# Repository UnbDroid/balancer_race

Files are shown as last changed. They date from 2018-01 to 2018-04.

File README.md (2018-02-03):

# Balancing Robot Race - RoboGames 2019

This is the Git repository containing all documents, code and schematics
used in the construction of DROID's robot.

### Cross-Compiling

Available at ```/ccdir```, the ```compile_rasp.sh``` file contains a script for
cross-compiling C code for the Raspberry Pi. It is a much faster process
than compiling code directly at the Raspberry.

Run ```$ sudo apt install gcc-arm-linux-gnueabi``` to install the ARM11 GCC.

All the library files needed must be provided. In this particular case,
we put them all in the same directory as the main code.

### Main Code and Threading

The main code, available at the ```main.c``` file under ```/code```, uses the ```pthread```
wrapper provided by the WiringPi library to parallelize the execution of the
code modules. Reference and documentation available at [WiringPi website](http://www.wiringpi.com).

### Information about DROID-UnB

DROID is a robotic competion team based in the university of Brasília - UnB.

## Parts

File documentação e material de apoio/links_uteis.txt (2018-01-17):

código para gyroscópio e acelerometro usando filtro de kalman:
https://github.com/TKJElectronics/Example-Sketch-for-IMU-including-Kalman-filter/tree/master/IMU/MPU6050
##obs: é o código referência para a criação do código mpu6050kalman.c em ~/testes.

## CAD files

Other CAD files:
documentação e material de apoio/motion_driver_6.12/msp430/eMD-6.0/Debug/core/driver/eMPL/inv_mpu_dmp_motion_driver.obj
documentação e material de apoio/motion_driver_6.12/msp430/eMD-6.0/Debug/core/driver/msp430/F5xx_F6xx_Core_Lib/HAL_PMM.obj
documentação e material de apoio/motion_driver_6.12/msp430/eMD-6.0/Debug/core/driver/msp430/msp430_interrupt.obj
documentação e material de apoio/motion_driver_6.12/msp430/eMD-6.0/Debug/core/driver/msp430/USB_API/USB_CDC_API/UsbCdc.obj
documentação e material de apoio/motion_driver_6.12/msp430/eMD-6.0/Debug/core/driver/msp430/USB_API/USB_Common/dma.obj
documentação e material de apoio/motion_driver_6.12/msp430/eMD-6.0/Debug/core/driver/msp430/USB_API/USB_HID_API/UsbHid.obj
documentação e material de apoio/motion_driver_6.12/msp430/eMD-6.0/Debug/core/driver/msp430/USB_API/USB_MSC_API/UsbMscStateMachine.obj
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

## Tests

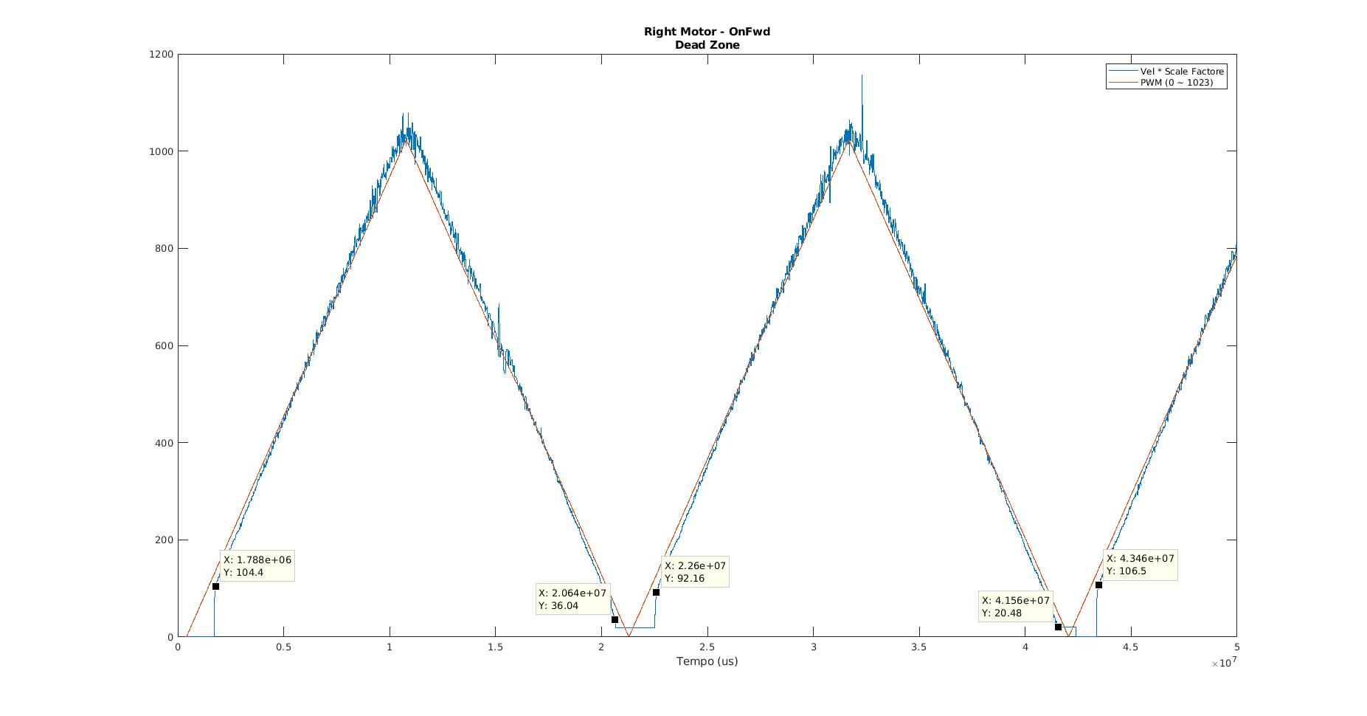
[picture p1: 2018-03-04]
MATLAB/plots/EncoderTest/dead_zone/Right Motor - OnFwd - DZ.jpg

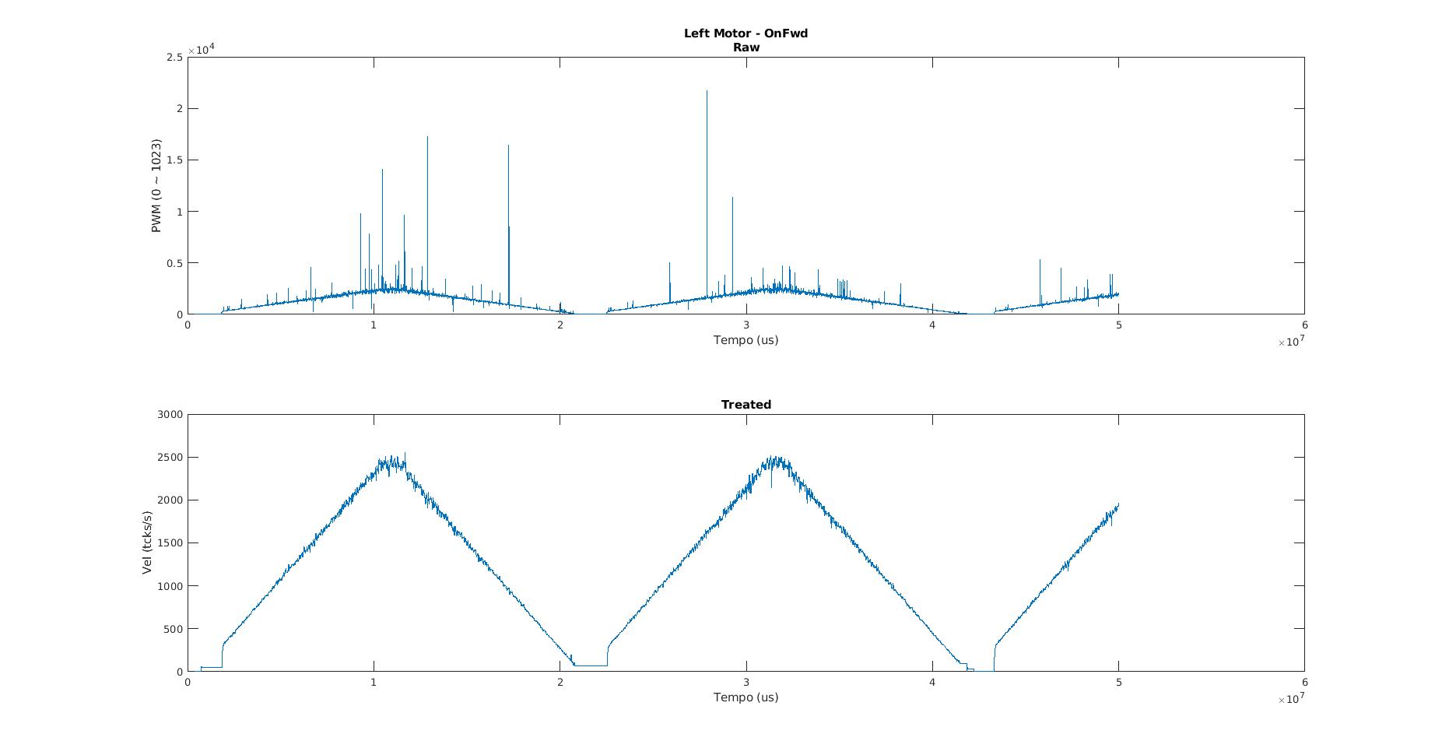
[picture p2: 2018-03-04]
MATLAB/plots/EncoderTest/dead_zone/Left Motor - OnFwd - tratamento.jpg

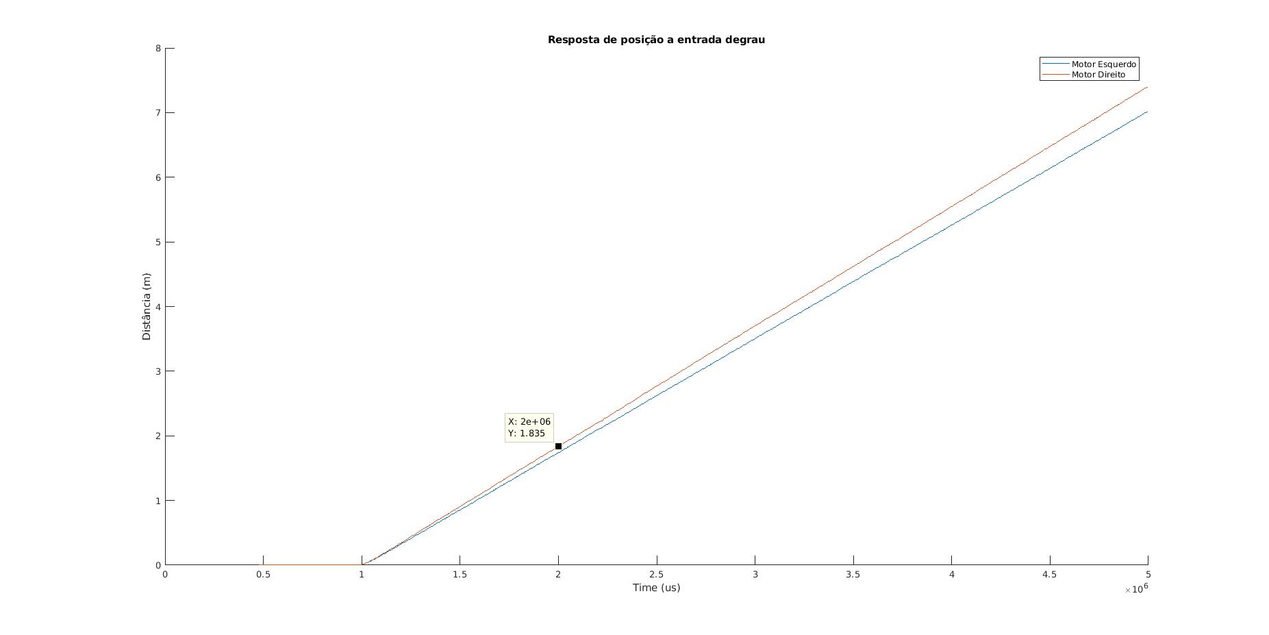
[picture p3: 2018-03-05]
MATLAB/plots/EncoderTest/posicao/degrau.jpg

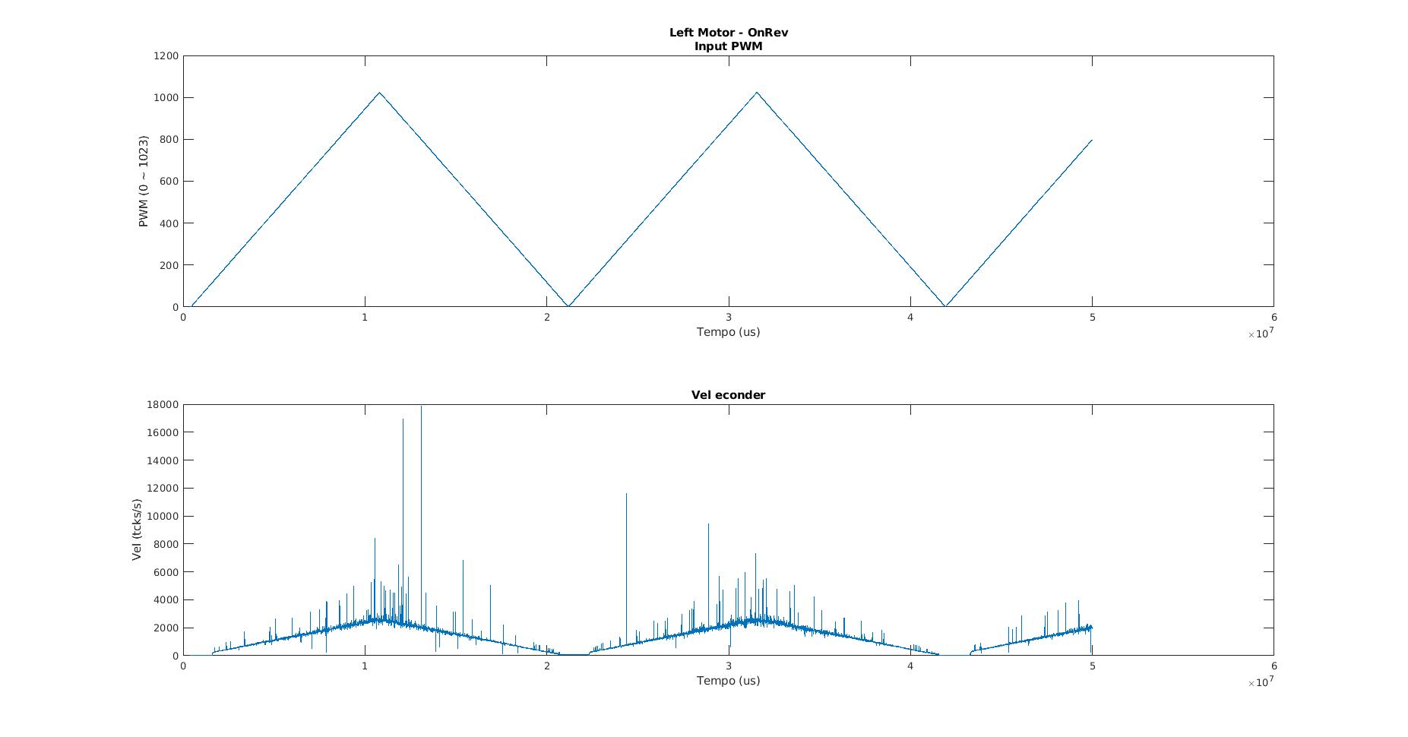
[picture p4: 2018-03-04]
MATLAB/plots/EncoderTest/dead_zone/Left Motor - OnRev - Raw.jpg

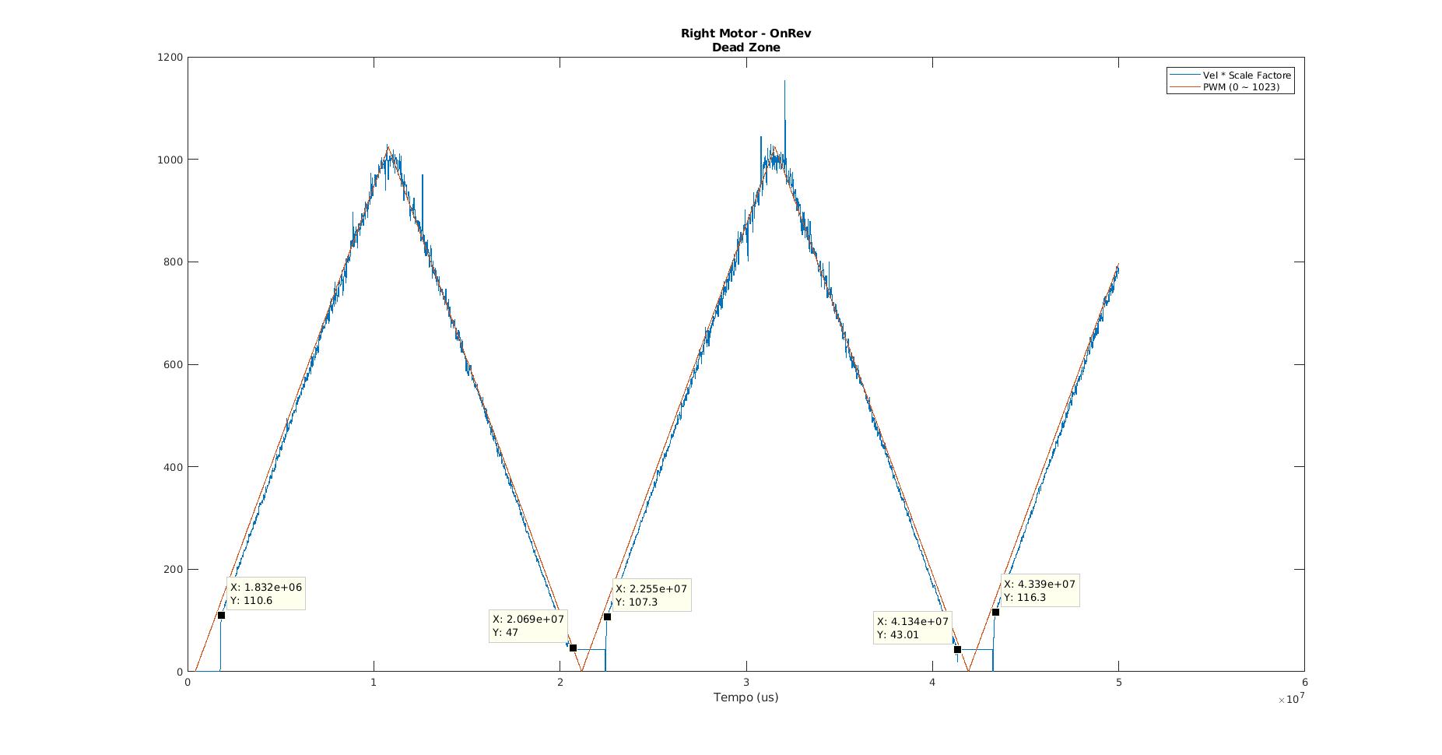
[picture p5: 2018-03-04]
MATLAB/plots/EncoderTest/dead_zone/Right Motor - OnRev - DZ.jpg

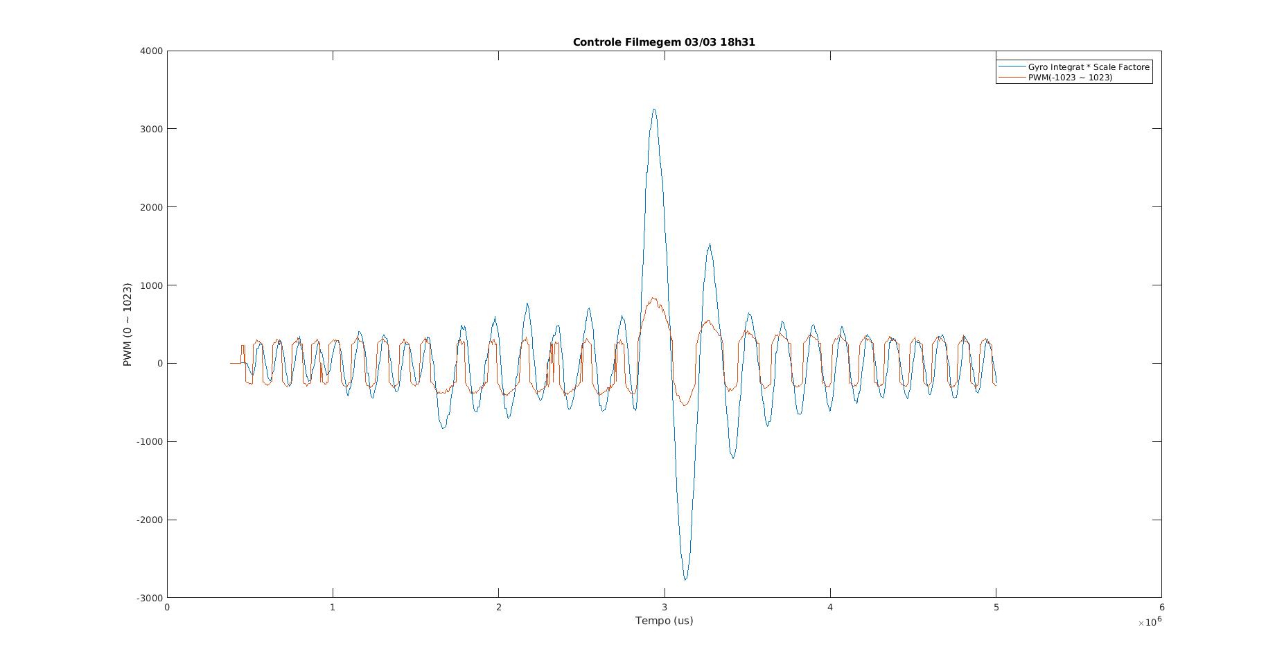
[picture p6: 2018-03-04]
MATLAB/plots/EncoderTest/controle/18h31.jpg

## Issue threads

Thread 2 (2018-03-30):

Fix integrator wind-up problem

bandreghetti, 2018-03-30:
PID integrator winds up if reference step is too big. Also it forces the gears when driver is off.

Proposed solution: integrate only if pwm output is not saturated.

luanharaujo, 2018-03-30:
Da para responder esse email?

Em sex, 30 de mar de 2018 às 17:43, Bruno Andreghetti Dantas <
notifications@github.com> escreveu:

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

Closed 2018-04-09.

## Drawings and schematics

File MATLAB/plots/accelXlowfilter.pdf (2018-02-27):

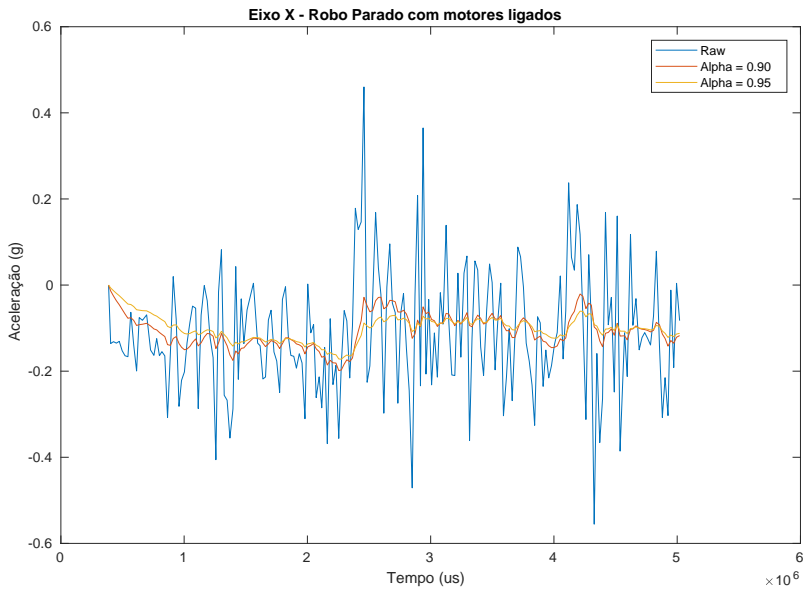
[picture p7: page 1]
Tempo (us); Aceleração (g); Raw Alpha = 0.90 Alpha = 0.95

Eixo X - Robo Parado com motores ligados

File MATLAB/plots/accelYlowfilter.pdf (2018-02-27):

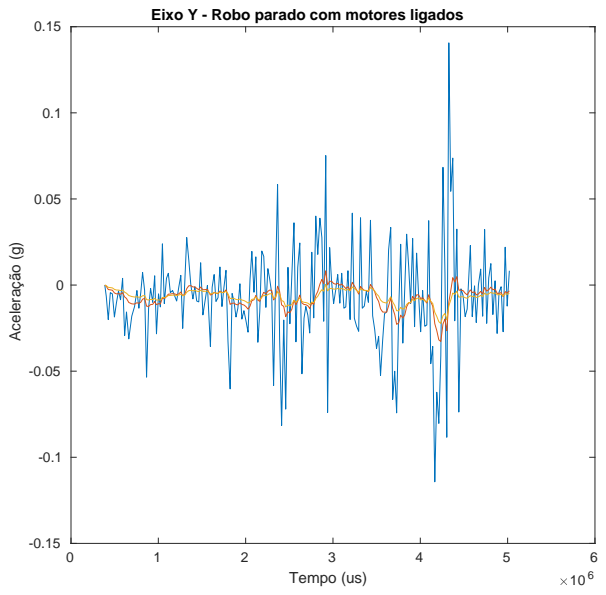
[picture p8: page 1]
Tempo (us); Aceleração (g)

Eixo Y - Robo parado com motores ligados

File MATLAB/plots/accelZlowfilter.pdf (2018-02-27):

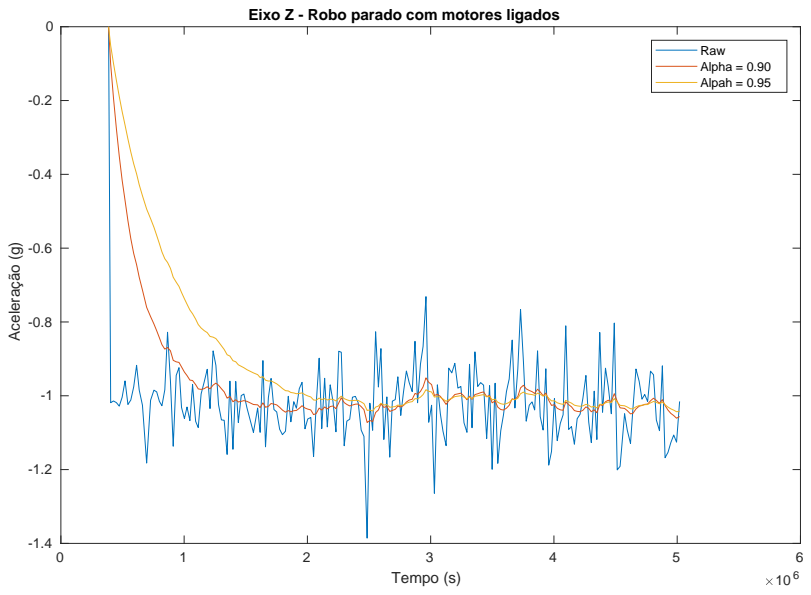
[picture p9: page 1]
Tempo (s); Aceleração (g); Raw Alpha = 0.90 Alpah = 0.95

Eixo Z - Robo parado com motores ligados

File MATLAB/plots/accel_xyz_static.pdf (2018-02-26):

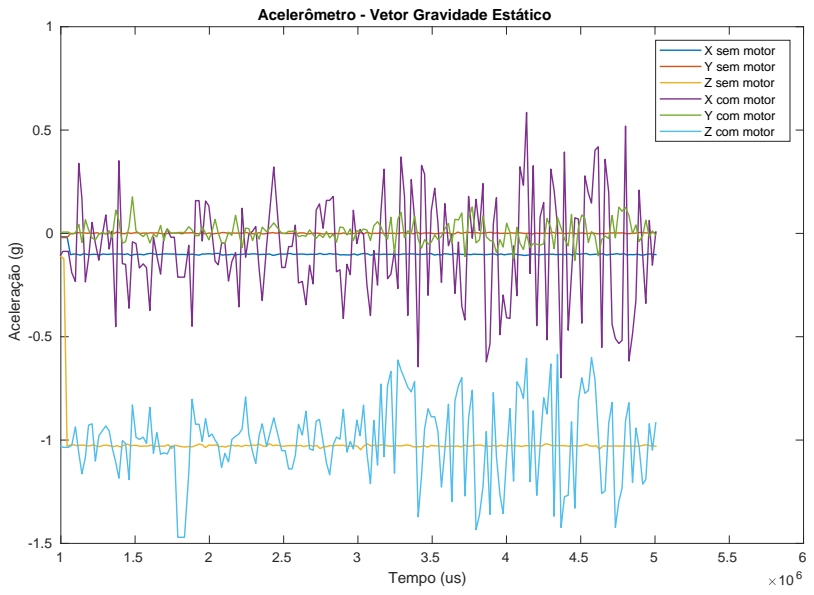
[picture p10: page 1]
Tempo (us); Aceleração (g); X sem motor Y sem motor Z sem motor X com motor Y com motor Z com motor

Acelerômetro - Vetor Gravidade Estático

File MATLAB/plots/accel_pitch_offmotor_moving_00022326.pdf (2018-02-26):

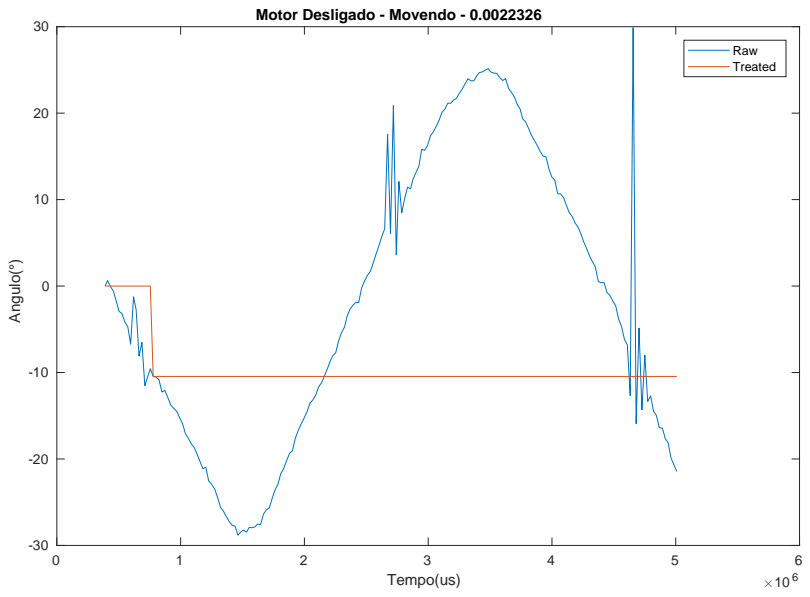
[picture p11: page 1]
Tempo(us); Angulo(°); Raw Treated

Motor Desligado - Movendo - 0.0022326

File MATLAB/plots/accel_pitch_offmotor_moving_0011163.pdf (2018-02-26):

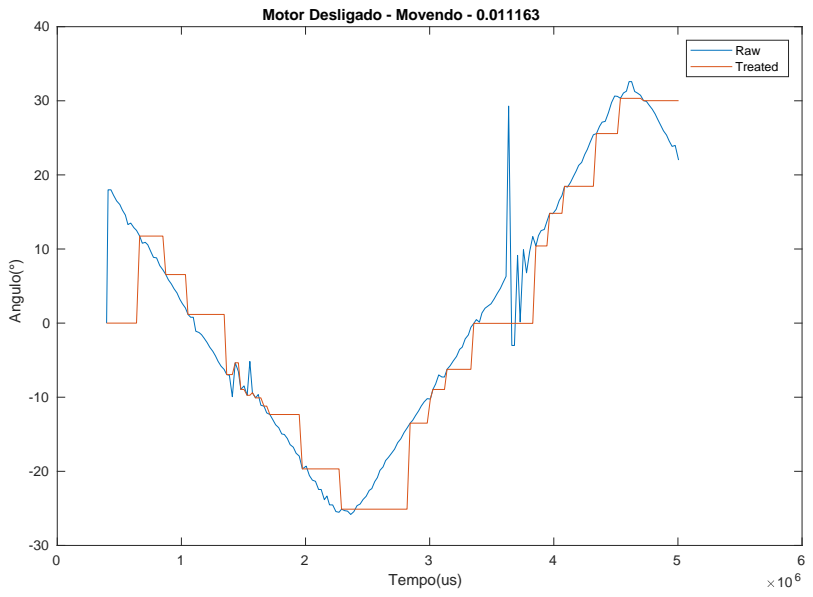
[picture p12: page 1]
Tempo(us); Angulo(°); Raw Treated

Motor Desligado - Movendo - 0.011163

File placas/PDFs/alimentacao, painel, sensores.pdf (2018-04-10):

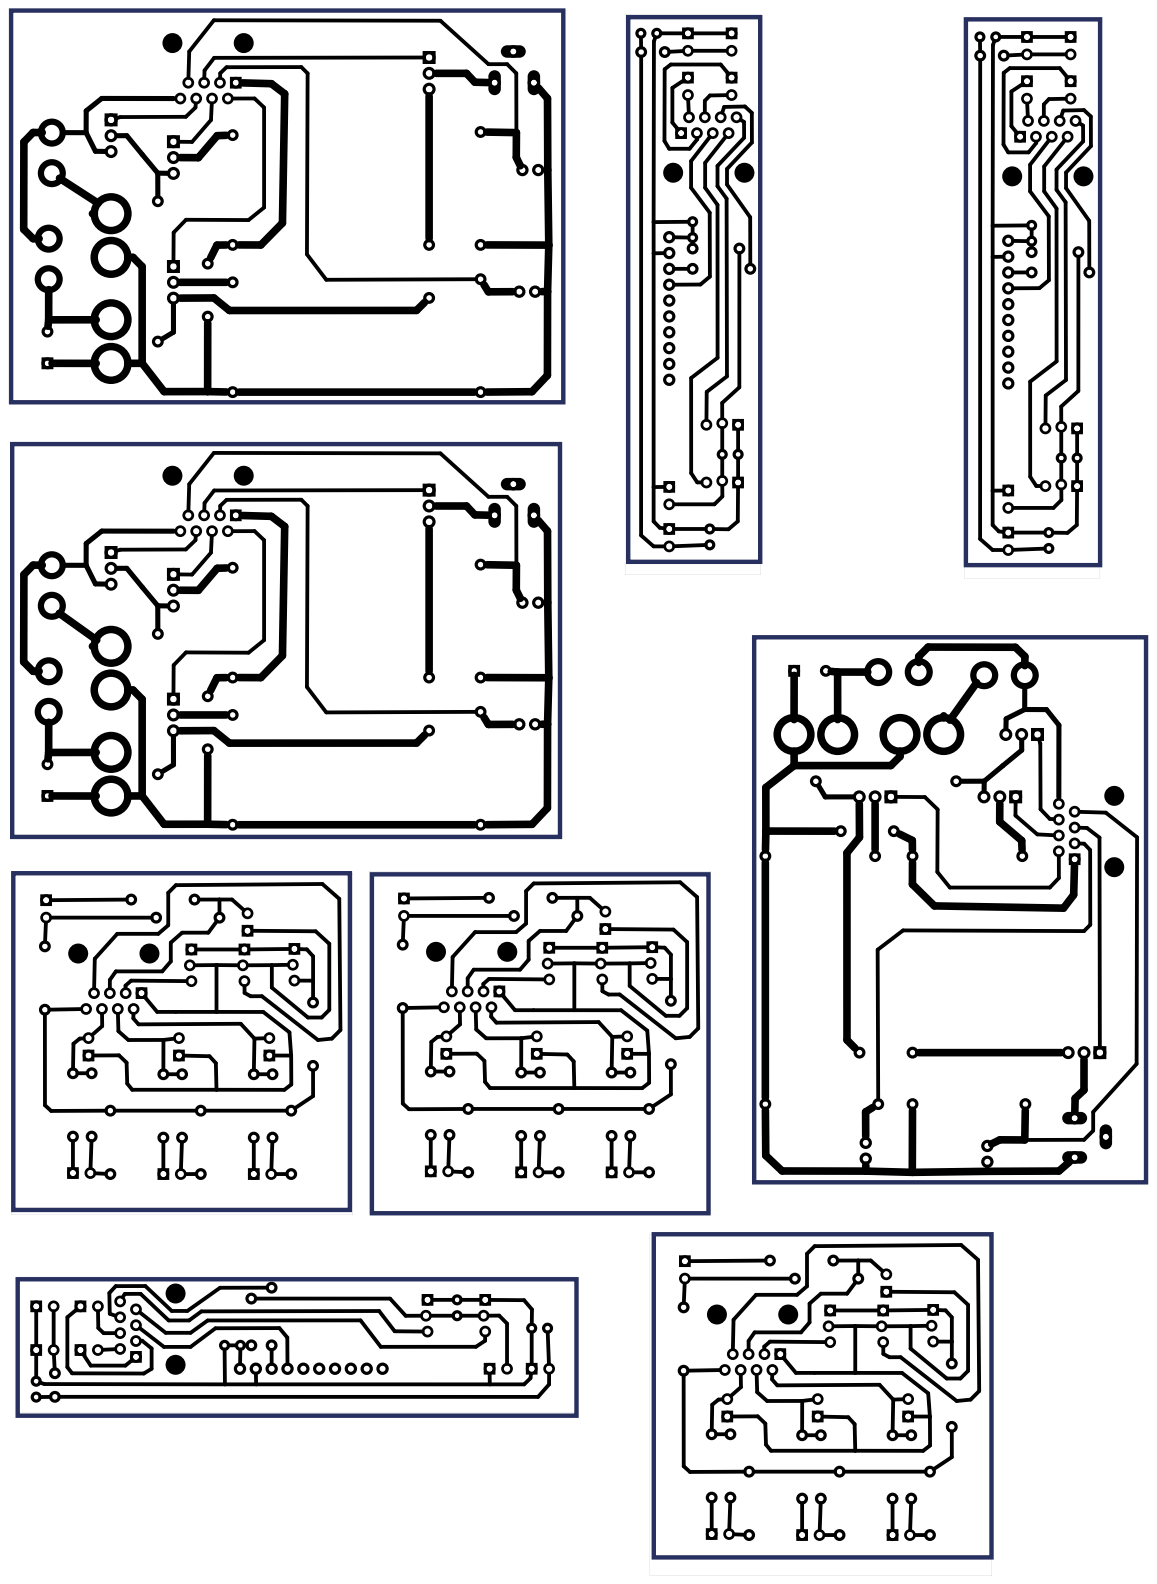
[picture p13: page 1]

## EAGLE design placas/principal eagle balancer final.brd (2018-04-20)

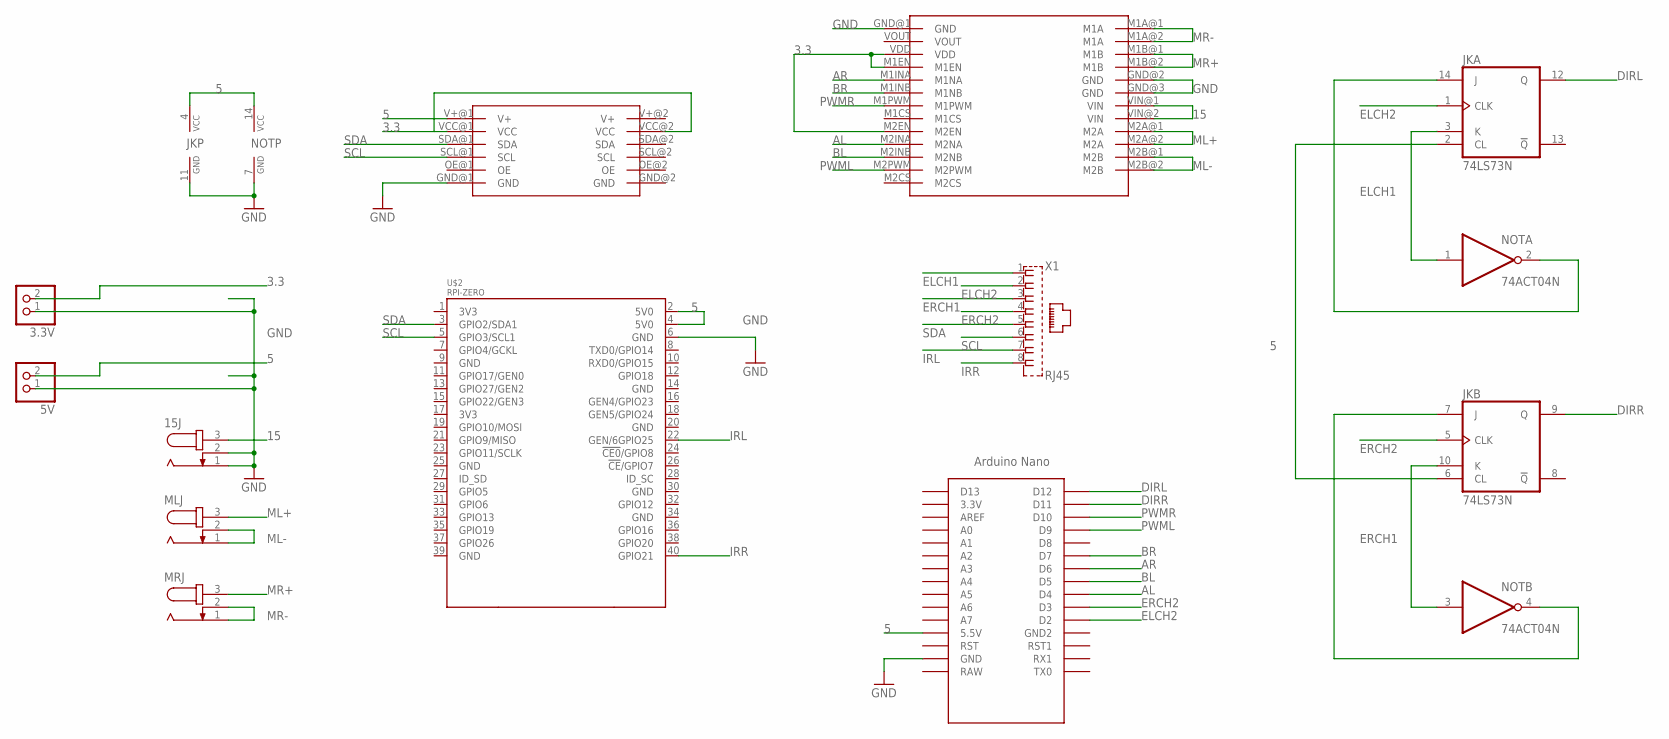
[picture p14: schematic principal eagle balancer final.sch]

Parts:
3.3V, 5V: PINHD-1X2; 1X02
15J: JACK-PLUG1; SPC4078
JK: 74LS73N; DIL14
MLJ: JACK-PLUG1; SPC4078
MRJ: JACK-PLUG1; SPC4078
NOT: 74ACT04N; DIL14
U$1: PCA; PCA_P
U$2: RPI-ZERO; RASPBERRYPI_BASTELSTUBE_V13_RASPI_BOARD_B+_FULL
U$3: VNH5019; VNH5019_P
U$4: NANO
X1: RJ45; RJ45_P

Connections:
3.3: 3.3V.2, U$1.VCC@1 (VCC), U$1.VCC@2 (VCC), U$3.M1EN, U$3.M2EN, U$3.VDD
5: 5V.2, JK.2 (CL), JK.4 (VCC), JK.6 (CL), NOT.14 (VCC), U$1.V+@1 (V+), U$2.2 (5V0), U$2.4 (5V0), U$4.5V (5.5V)
15: 15J.3, U$3.VIN@1 (VIN), U$3.VIN@2 (VIN)
AL: U$3.M2INA (M2NA), U$4.D4
AR: U$3.M1INA (M1NA), U$4.D6
BL: U$3.M2INB (M2NB), U$4.D5
BR: U$3.M1INB (M1NB), U$4.D7
DIRL: JK.12 (Q), U$4.D12
DIRR: JK.9 (Q), U$4.D11
ELCH1: JK.3 (K), NOT.1 (I), X1.1
ELCH2: JK.1 (CLK), U$4.D2, X1.2
ERCH1: JK.10 (K), NOT.3 (I), X1.3
ERCH2: JK.5 (CLK), U$4.D3, X1.4
GND: 3.3V.1, 5V.1, 15J.1, 15J.2, JK.11 (GND), NOT.7 (GND), U$1.GND@1 (GND), U$2.6 (GND), U$3.GND@1 (GND), U$3.GND@2 (GND), U$3.GND@3 (GND), U$4.GND
IRL: U$2.22 (GEN/6GPIO25), X1.7
IRR: U$2.40 (GPIO21), X1.8
ML+: MLJ.3, U$3.M2A@1 (M2A), U$3.M2A@2 (M2A)
ML-: MLJ.1, MLJ.2, U$3.M2B@1 (M2B), U$3.M2B@2 (M2B)
MR+: MRJ.3, U$3.M1B@1 (M1B), U$3.M1B@2 (M1B)
MR-: MRJ.1, MRJ.2, U$3.M1A@1 (M1A), U$3.M1A@2 (M1A)
unnamed: JK.14 (J), NOT.2 (O)
unnamed: JK.7 (J), NOT.4 (O)
PWML: U$3.M2PWM, U$4.D9
PWMR: U$3.M1PWM, U$4.D10
SCL: U$1.SCL@1 (SCL), U$2.5 (GPIO3/SCL1), X1.6
SDA: U$1.SDA@1 (SDA), U$2.3 (GPIO2/SDA1), X1.5

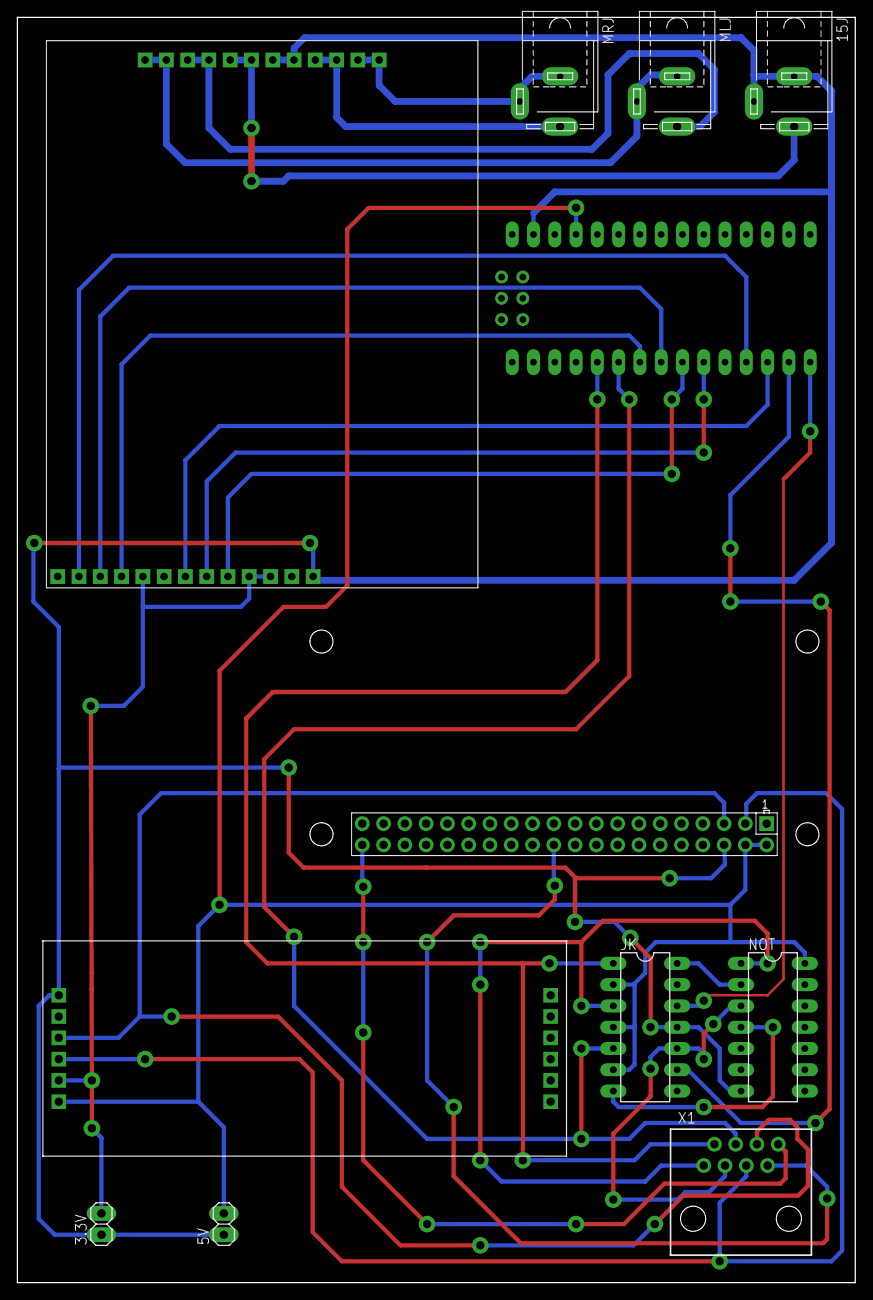
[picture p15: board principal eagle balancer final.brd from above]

Board: 2 copper layers, 100.0 x 151.0 mm, 12 parts (0 on the bottom side), 26 nets.

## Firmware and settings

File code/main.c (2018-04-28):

#include <stdio.h>
#include <stdlib.h>
#include <wiringPi.h>
#include <unistd.h>
#include <string.h>
#include <ctype.h>
#include <math.h>
#include "jstick.c"
#include "led.c"
#include "sensors.c"
#include "motor.c"
#include "debug.c"


struct debug_data debug;	// struct containing all robot values
							// for debugging purposes

int keep_running = 1;	// end of program flag. it is controlled by the
						// joystick thread. if set to 0, all threads will
						// finish up and set their own flags to 1 so that
						// the main program can clean everything up and end.

int main_finished = 1, led_finished = 1, joystick_finished = 1;
int debug_finished = 1, sensors_finished = 1, motors_finished = 1;
int matlab_finished = 1, supervisory_finished = 1, plot_finished = 1;

int shutdown_flag = 0, reboot = 0, close_program=0;	// flags set by joystick
													// commands so that the
													// program knows what to
													// do when finishing up.

int halt = 1;

/*
This is the main thread. In it, we are supposed to put everything that doesn't
belong in the infrastructure threads below it. Generally, it is used to test
new features using the joystick controller.
*/

/*
//Butterworth Filter - A manteiga que vale
#define A0 1.000000000000000
#define A1 -1.968427786938518
#define A2 1.735860709208886
#define A3 -0.724470829507362
#define A4 0.120389599896245
#define B0 0.010209480791203
#define B1 0.040837923164813
#define B2 0.061256884747219
#define B3 0.040837923164813
#define B4 0.010209480791203

double A[5] = {A0, A1, A2, A3, A4};
double B[5] = {B0, B1, B2, B3, B4};
double bw_filtered[4];
double bw_raw[5];
*/

#define DEV_ACC_Z_OVER_X 97.1256
// motor grande
//float KP = 385; //325;
//float KD = 15; //10;
//float KI = 20;

double EULER = 2.718281828459045;

// motor pequeno
float KP = 0.2;//125; //325;
float KD = 0.02;//2.5;
float KI = 0.007;//0.7;

float KPvel = 3.1;//1;//1;
float KDvel = 0.01;//0;//10;
float KIvel = 1.15;//1.7;//5;

float KPome = 1;
float KDome = 0.025;
float KIome = 2;

float teta = 0, teta_linha, teta_raw;
float gyroIntegrate = 0, old_gyroIntegrate = 0;
int pot = 0, dir;
float GK;
float dev_teta;
unsigned long long int temp = 0;
int flag;
float tetaIntegrat = 0;


// VARIAVEIS USADAS NO CONTROLE.
double speed = 0;

double vel_ref = 0;
double vel_erro = 0, vel_erro_old = 0, vel_erro_integrate = 0, vel_ref_integrate = 0, vel_erro_derivate = 0;
double vel_med = 0;
unsigned long long int vel_time, vel_time_old, vel_dt;

double req_tilt = 0, req_tilt_old = 0, req_tilt_linha = 0;
double tilt_erro = 0, tilt_erro_integrate = 0, tilt_erro_linha = 0;

double omega = 0, omega_integrate = 0, omega_ref_integrate = 0;
double omega_erro = 0, omega_erro_old = 0, omega_erro_integrate = 0, omega_erro_derivate = 0;
double speed_dir = 0;
double omega_ref = 0;

unsigned long long int ref_crono = 0, ref_crono_set = 0, ref_time = 0;
double diff = 0, ref = 0, atual = 0, ref_old = 0;
double time_k = 38.918203; // ln(1-%a/%a)/-ta // %a = porcentagem que deseja obter apos decorrido tempo ta. ta = tempo necessario para chegar na porcentagem desejada em segundos.
double ta = 0.12;
double scurve_extra_time = 0.06; // Tempo extra do scurve pra ficar próximo da referência.

unsigned long long int ref_crono_omega = 0, ref_crono_set_omega = 0, ref_time_omega = 0;
double diff_omega = 0, atual_omega = 0, omega_ref_old = 0;
double s_omega_ref = 0;
double time_k_omega = 382.926654; // ln(1-%a/%a)/-ta // %a = porcentagem que deseja obter apos decorrido tempo ta. ta = tempo necessario para chegar na porcentagem desejada em segundos.
double ta_omega = 0.012;
double scurve_extra_time_omega = 0.006; // Tempo extra do scurve pra ficar próximo da referência.

double lpf_vel_med[2];
double lpf_omega[2];

double LPFgain = 0.02;
double LPFgainOmega = 0.05;

PI_THREAD(main_thread)
{
	main_finished = 0;
	piHiPri(0);
	
	teta = 0;
	gyroIntegrate = 0;
	old_gyroIntegrate = 0;
	pot = 0;
	temp = 0;
	tetaIntegrat = 0;

	speed = 0;

	vel_ref = 0;
	vel_erro = 0;
	vel_erro_old = 0;
	vel_erro_integrate = 0;
	vel_ref_integrate = 0;
	vel_erro_derivate = 0;
	vel_med = 0;

	req_tilt = 0;
	req_tilt_old = 0;
	req_tilt_linha = 0;
	tilt_erro = 0;
	tilt_erro_integrate = 0;
	tilt_erro_linha = 0;

	omega = 0;
	omega_integrate = 0;
	omega_ref_integrate = 0;
	omega_erro = 0;
	omega_erro_old = 0;
	omega_erro_integrate = 0;
	omega_erro_derivate = 0;
	speed_dir = 0;
	omega_ref = 0;

	ref_crono = 0;
	ref_crono_set = 0;
	ref_time = 0;
	diff = 0;
	ref = 0;
	atual = 0;
	ref_old = 0;

	ref_crono_omega = 0;
	ref_crono_set_omega = 0;
	ref_time_omega = 0;
	diff_omega = 0;
	atual_omega = 0;
	omega_ref_old = 0;
	s_omega_ref = 0;

	lpf_vel_med[0] = 0;
	lpf_vel_med[1] = 0;

	lpf_omega[0] = 0;
	lpf_omega[1] = 0;

	vel_erro_integrate = 0;
	vel_ref_integrate = 0;
	tilt_erro_integrate = 0;
	omega_erro_integrate = 0;
	omega_ref_integrate = 0;

	set_led_state(HALT, OFF);
	delay(1000);
	teta = RAD2DEG*atan2(imu.accel.filteredZ, imu.accel.filteredX);
	printf("%f\n", teta);
	//gyroIntegrate = teta;
	gyroIntegrate = teta - (-97.567947);
	ref_crono_set = micros();


	while(keep_running && !halt)
	{
		//lendo o acell com filtro
		//teta = (RAD2DEG*atan2(imu.accel.filteredZ,imu.accel.filteredX)/*- (-95.416)*/);
	
		teta_linha = imu.gyro.treatedY - (-0.148855);//(-0.131567);

		if(temp != imu.last_update)
		{
			/*
			if(temp == 0)
			{
				//offset = (RAD2DEG*atan2(imu.accel.treatedZ,imu.accel.treatedX));
			}
			*/
			temp = imu.last_update;
			old_gyroIntegrate = gyroIntegrate;
			gyroIntegrate = gyroIntegrate+teta_linha*imu.dt;
			//teta = teta+teta_linha*imu.dt;
		}
		//teta = (RAD2DEG*atan2(imu.accel.filteredZ ,imu.accel.filteredX)) - (-97.045494);
		//teta = (RAD2DEG*atan2(imu.accel.treatedZ ,imu.accel.treatedX)) - (-95.916);
		//pot = (int)(teta*KP + teta_linha*KD);

		//---------------------------------------------------------------------------------------------------------------------
		// COMANDO VELOCIDADE POR JOYSTICK.
		if(js.lanalog.up > 0)
		{
			ref = 0.0019550342*js.lanalog.up;//0.0000127077*js.lanalog.up;
		}
		else if (js.lanalog.down > 0)
		{
			ref = -0.0019550342*js.lanalog.down;//-0.0000127077*js.lanalog.down;
		}
		else 
		{
			ref = 0;
		}

		ref_crono = micros();
		ref_time = ref_crono - ref_crono_set;
		
		if (ref != ref_old){
			diff = ref - vel_ref;
			atual = vel_ref;
			ref_crono_set = micros();
			ref_time = 0;

			ref_old = ref;
		}

		if (((double)ref_time)/1000000 < (2*ta + scurve_extra_time)){
			vel_ref = atual + diff*(1/(1 + pow(EULER, -time_k*(-ta + ((double)ref_time)/1000000))));
		} else {
			vel_ref = ref;
		}
		//vel_ref = 1/(1 + pow(EULER, -time_k*(-0.2 + ((double)ref_time)/1000000))); // S-CURVE FUNCIONANDO.
		//vel_ref = ref;

		//---------------------------------------------------------------------------------------------------------------------
		// PRIMEIRO CONTROLADOR. VEL -> TILT.
		vel_med = (left_motor.speed + right_motor.speed)/2;
		lpf_vel_med[0] = vel_med*LPFgain + lpf_vel_med[1]*(1-LPFgain);
		lpf_vel_med[1] = lpf_vel_med[0];
		vel_time_old = vel_time;
		vel_time = micros();
		vel_dt = vel_time - vel_time_old;

		vel_erro_old = vel_erro;
		vel_erro = vel_ref - lpf_vel_med[0];
		//vel_ref_integrate += vel_ref;
		vel_erro_integrate += vel_erro*((double)vel_dt)/1000000;
		//vel_erro_integrate = vel_ref_integrate - (left_motor.displacement + right_motor.displacement)/2;
		vel_erro_derivate = (vel_erro - vel_erro_old)/vel_dt;
		
		req_tilt_old = req_tilt;
		
		req_tilt = -(vel_erro*KPvel + vel_erro_integrate*KIvel + vel_erro_derivate*KDvel);
		
		//---------------------------------------------------------------------------------------------------------------------	
		// SEGUNDO CONTROLADOR. TILT -> PWM. 
		tilt_erro = req_tilt - gyroIntegrate;
		tilt_erro_integrate += tilt_erro;
		req_tilt_linha = (req_tilt - req_tilt_old)/vel_dt;
		tilt_erro_linha = req_tilt_linha - teta_linha;
	 	
	 	speed = (tilt_erro*KP + tilt_erro_linha*KD + tilt_erro_integrate*KI);

	 	//---------------------------------------------------------------------------------------------------------------------
	 	// COMANDO ROTACAO POR JOYSTICK.
	 	if(js.ranalog.left > 0)
		{
			omega_ref = 0.0016617791*js.ranalog.left;
		}
		else if (js.ranalog.right > 0)
		{
			omega_ref = -0.0016617791*js.ranalog.right;
		}
		else 
		{
			omega_ref = 0;
		}
	 	//omega_ref = 5;

		ref_crono_omega = micros();
		ref_time_omega = ref_crono_omega - ref_crono_set_omega;
		
		if (omega_ref != omega_ref_old){
			diff_omega = omega_ref - s_omega_ref;
			atual_omega = s_omega_ref;
			ref_crono_set_omega = micros();
			ref_time_omega = 0;

			omega_ref_old = omega_ref;
		}

		if (((double)ref_time_omega)/1000000 < (2*ta_omega + scurve_extra_time_omega)){
			s_omega_ref = atual_omega + diff_omega*(1/(1 + pow(EULER, -time_k_omega*(-ta_omega + ((double)ref_time_omega)/1000000))));
		} else {
			s_omega_ref = omega_ref;
		}

	 	//---------------------------------------------------------------------------------------------------------------------
	 	// TERCEIRO CONTROLADOR. DIRECAO.
	 	omega = right_motor.speed - left_motor.speed;
	 	lpf_omega[0] = omega*LPFgainOmega + lpf_omega[1]*(1-LPFgainOmega);
		lpf_omega[1] = lpf_omega[0];
	 	omega_integrate = right_motor.displacement - left_motor.displacement;
	 	omega_ref_integrate += s_omega_ref*((double)vel_dt)/1000000;

	 	omega_erro_old = omega_erro;
	 	omega_erro = s_omega_ref - lpf_omega[0];
	 	omega_erro_integrate = omega_ref_integrate - omega_integrate;
	 	omega_erro_derivate = (omega_erro - omega_erro_old)/(((double)vel_dt)/1000000);

	 	speed_dir = omega_erro*KPome + omega_erro_integrate*KIome + omega_erro_derivate*KDome;

	 	//---------------------------------------------------------------------------------------------------------------------
	 	// COMANDO PARA O ARDUINO. 
		setMotorSpeed(LMOTOR, speed - speed_dir);
		setMotorSpeed(RMOTOR, speed + speed_dir);
		write_motors();

		delay(5);
	}
	setMotorSpeed(LMOTOR, 0);
	setMotorSpeed(RMOTOR, 0);
	write_motors();
	set_led_state(HALT, ON);
	main_finished = 1;
}

#define SAMPLE_TIME 5
#define NPLOTVARS 15
double plotvar[NPLOTVARS] = {};
PI_THREAD(plot)
{
	plot_finished = 0;
	FILE *fp;
	unsigned long long int now, last_fprintf = 0;
	int i = 0;
	char fname[40];
	while(keep_running)
	{
		while(!js.B && keep_running) delay(20);
		while(js.B && keep_running) delay(20);
		
		i = 0;
		if (keep_running)
		{
			do {
				snprintf(fname, 40, "/home/pi/datalog/plot_data_%03d", i);
				++i;
			} while(exists(fname));
			fp = fopen(fname, "w");
			
			set_led_state(PLOT, ON);
			while(!js.B && keep_running)
			{
				now = micros();
				if(now - last_fprintf > SAMPLE_TIME*1000)
				{
					last_fprintf = now;

					plotvar[0] = lpf_vel_med[0];
					plotvar[1] = vel_ref;
					plotvar[2] = lpf_omega[0];
					plotvar[3] = vel_erro_integrate;

					fprintf(fp, "%lld ", now);
					for(i = 0; (i < NPLOTVARS-1 && plotvar[i+1] == plotvar[i+1]); ++i)
					{
						fprintf(fp, "% f ", plotvar[i]);
					}
					if(plotvar[i] == plotvar[i])
					{
						fprintf(fp, "% f;\n", plotvar[i]);
					}
				}
			}
			fclose(fp);
			printf("Saved data to file %s\n", fname);
			set_led_state(PLOT, OFF);
			while(js.B && keep_running) delay(20);
		}
	}
	plot_finished = 1;
}

/*
This is the joystick thread. It runs the code behind reading and interpreting
joystick commands. The joystick is the primary way of commanding the robot and
will be eventually used as safety trigger. Aside from that, it allows the
operator to control the robot without the need for opening a terminal.
All joystick support functions available in the jstick.c file.
*/
PI_THREAD(joystick)
{
    joystick_finished = 0;
	piHiPri(0);

    set_led_state(BLUETOOTH, ON);
    init_joystick(&js, devname);
    set_led_state(BLUETOOTH, OFF);

	// START+SELECT finishes the program
    while((!(js.select && js.start)) && (keep_running)) 
    {
		if(js.disconnect)
        {
        	halt = 1;
			setMotorSpeed(LMOTOR, 0);
			setMotorSpeed(RMOTOR, 0);
			write_motors();

			set_led_state(BLUETOOTH, ON);
		    init_joystick(&js, devname);
		    set_led_state(BLUETOOTH, OFF);
		}
		if(js.LT > 100 || js.RT > 100)
		{
			halt = 0;
		} else {
			halt = 1;
			setMotorSpeed(LMOTOR, 0);
			setMotorSpeed(RMOTOR, 0);
			write_motors();
		}
		if(!halt && main_finished)
		{
			piThreadCreate(main_thread);
			while(main_finished);
		}
        update_joystick(&js);
	}
	// If a D-Pad key is pressed along with START+SELECT when finishing
	// the program, special finishing up routines are called inside the
	// clean_up() function. They are:

	// DOWN+START+SELECT: shuts the Raspberry Pi Zero W down
	if(js.dpad.down) shutdown_flag = 1;
	// UP+START+SELECT: reboots the Raspberry Pi Zero W
	if(js.dpad.up) reboot = 1;
	// LEFT+START+SELECT: closes the program, not calling the watcher
	if(js.dpad.left) close_program = 1;

	keep_running = 0;
	joystick_finished = 1;
}

/*
This is the LED thread. It runs the LED above the robot, used for debugging
and for informing the operator about the robot's current status.
All LED support functions are available in the led.c file.
*/
PI_THREAD(led)
{
	led_finished = 0;
	piHiPri(0);
	init_led();
	while(keep_running)
	{
		update_led();
		delay(10);
	}
	led_finished = 1;
}

/*
This is the sensors thread. It keeps the robot's sensors updated at a
(supposedly) steady rate.
*/
#define SENSORS_UPDATE_RATE 10 // defined in milliseconds
PI_THREAD(sensors)
{
	sensors_finished = 0;
	unsigned long long int last_update, now_time;
	piHiPri(0);
	while(keep_running)
	{
		now_time = micros();
		if(now_time - last_update > 1000*SENSORS_UPDATE_RATE)
		{
			last_update = now_time;
			//update_ir();
			update_imu();
			//update_complementar();
			//update_kalman();
		} else {
			delayMicroseconds(100);
		}
	}
	sensors_finished = 1;
}

PI_THREAD(motors)
{
	motors_finished = 0;
	piHiPri(0);
	
	while(keep_running)
	{
		getValidData();
		storeValidData();
	}
	motors_finished = 1;
	
}

/*
This is the debug thread. It runs the debug screen code and is only run if the
program is called with the -d or --debug parameter. For example:
pi@raspberrypi $ sudo ./main -d
*/
PI_THREAD(debug_thread)
{
	debug_finished = 0;
	piHiPri(0);
	init_debug();
	while(keep_running)
	{
		debug.js = js;
		debug.left_motor = left_motor;
		debug.right_motor = right_motor;
		debug.ir = ir;
		debug.imu = imu;
		debug.led_state = led_state;
		update_debug(&debug);
		delay(100);
	}
	printf("\033[%d;%dH\n", 43, 1);
	debug_finished = 1;
}

/*
This is the supervisory system support thread. It runs separately from the
debug thread although it shouldn't. The reason for that is that the socket
server functions halt the program if there is no supervisory client running.
*/
PI_THREAD(supervisory)
{
	piHiPri(0);
	while(keep_running)
	{
		init_supervisory();
		supervisory_finished = 0;
		do{
			delay(10);

			debug.js = js;
			debug.left_motor = left_motor;
			debug.right_motor = right_motor;
			debug.ir = ir;
			debug.imu = imu;
			debug.led_state = led_state;
		} while(keep_running && (send_superv_message(&debug) != -1));
	}
	supervisory_finished = 1;
}

PI_THREAD(matlab)
{
	piHiPri(0);
	init_matlab();
	matlab_finished = 0;
	while(keep_running)
	{
		debug.js = js;
		debug.left_motor = left_motor;
		debug.right_motor = right_motor;
		debug.ir = ir;
		debug.imu = imu;
		debug.led_state = led_state;

		send_matlab_message(&debug);
		delay(10);
	}
	matlab_finished = 1;
}

int am_i_su()
{
    if(geteuid())
    	return 0;
    return 1;
}

void clean_up()
{
	int nao_terminou = 1;
	setMotorSpeed(LMOTOR, 0);
	setMotorSpeed(RMOTOR, 0);
	write_motors();
	set_color(RED, 255);
	light_rgb();
	while(!led_finished);
	set_color(RED, 255);
	light_rgb();
	do {
		nao_terminou = !(main_finished && joystick_finished && debug_finished && sensors_finished && supervisory_finished && plot_finished && motors_finished); 
		/*
		printf("%d...", main_finished);
		printf("%d...", joystick_finished);
		printf("%d...", debug_finished);
		printf("%d...", sensors_finished);
		printf("%d...", supervisory_finished);
		printf("%d...", plot_finished);
		printf("%d...", motors_finished);
		printf("%d...\n", nao_terminou);
		*/
	} while(nao_terminou);
	set_color(WHITE, 255);
	light_rgb();

	if(shutdown_flag) system("sudo shutdown now&");
	else if(reboot) system("sudo shutdown -r now&");
	else if (!close_program)
	{
		if(debug.debug_flag) system("sudo /home/pi/ccdir/watcher -d&");
		else system("sudo /home/pi/ccdir/watcher&");
	}
}

int main(int argc, char* argv[])
{
	if(!am_i_su())
	{
		printf("Restricted area. Super users only.\n");
		return 0;
	}

	wiringPiSetupPhys();

	for(i = 0; i < NPLOTVARS; ++i)
	{
		plotvar[i] = sqrt(-1);
	}
	piThreadCreate(plot);

	debug.debug_flag = 0;
	if(argc > 1)
	{
		for(i = 1; i < argc; ++i)
		{
			if(strcmp(argv[i], "-d") == 0 || strcmp(argv[i], "--debug") == 0)
			{
				debug.debug_flag = 1;
			}
		}
		if(debug.debug_flag)
		{
			piThreadCreate(debug_thread);
		}
	}

	init_motors();
	init_sensors();

	piThreadCreate(main_thread);
	piThreadCreate(motors);
	piThreadCreate(sensors);
	piThreadCreate(joystick);
	piThreadCreate(led);

	piThreadCreate(supervisory);
	piThreadCreate(matlab);

	while(keep_running) delay(100);
	clean_up();

	return 0;
}

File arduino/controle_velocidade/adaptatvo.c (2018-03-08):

 /* read a rotary encoder with interrupts
   Encoder hooked up with common to GROUND,
   encoder0PinA to pin 2, encoder0PinB to pin 4 (or pin 3 see below)
   it doesn't matter which encoder pin you use for A or B  
   uses Arduino pullups on A & B channel outputs
   turning on the pullups saves having to hook up resistors 
   to the A & B channel outputs 
*/ 

// Includes ------------------------------------------------------------------------------------------------

// SD card
#include <SD.h>

// Cálculos
#include <math.h>

// Defines -------------------------------------------------------------------------------------------------

// SD card
#define CS 53

// Encoders esquerda
#define encoder0PinA 18
#define encoder0PinB 19

// Encoders direita
#define encoder1PinA 2
#define encoder1PinB 3

// Calculo de velocidade
#define pi 3.14159265359f

// Controle de velocidade
#define limiar_erro_velocidade 0.07f
#define POT_MAX_ESQUERDA 161
#define POT_MAX_DIREITA 161
#define POT_MIN_ESQUERDA 11
#define POT_MIN_DIREITA 11
#define Kp_esquerda 6.5f
#define Ki_esquerda 0.05f
#define Kd_esquerda 0.1f
#define Kp_direita 6.5f
#define Ki_direita 0.05f
#define Kd_direita 0.1f

// Controle remoto
#define CHANEL1 22
#define CHANEL2 24
#define CHANEL3 26

// Driver
#define IN1_D 10
#define IN2_D 9 
#define IN1_E 13
#define IN2_E 12

#define PWM_D 8
#define PWM_E 11

// Variáveis ----------------------------------------------------------4-----------------------------------

// SD card
const int chipSelect = CS;
int dataString = 0;
bool abriu = true;
char nomearquivo[] = "datalog1.txt";

// Encoders
volatile long encoder0Pos = 0; //esquerda
volatile long encoder1Pos = 0; //direita
double voltas_esquerda = 0, voltas_esquerda_anterior = 0;
double voltas_direita = 0, voltas_direita_anterior = 0;

// Cálculo de velocidade
float velocidade_esquerda = 0;
float velocidade_direita = 0;
double tempo;
double tempo_aux;

// Controle de velocidade
float velocidade_Referencia = 3;
float velocidade_Referencia_anterior = 0;
bool trocar_sentido = false;
bool foward = true;
bool back = false;
bool left = false;
bool right = false;
bool left_eixo = false;
bool right_eixo = false;

float theta1_esquerda = 0.50;
float theta2_esquerda = 0.25;
float yTv_esquerda = 0.08;

float theta1_direita = 0.40;
float theta2_direita = 0.15;
float yTv_direita = 0.07;

float velocidade_esquerda_modelo = 0;
float velocidade_direita_modelo = 0;
float pot_esquerda_teste = 0;
float pot_direita_teste = 0; 
float tensaomotor_esquerda = 0;
float tensaomotor_direita = 0;
float tensao_bateria = 12;

// Driver
float pot_direita = 0;
float pot_esquerda = 0;

// Ler int do buffer serial
float valor = 0;

// Usar o controle remoto
int ch1;
int ch2;
int ch3;

//Funcoes de setup dos módulos --------------------------------------------------------------------------------------------------------------

// Driver

void start_DRIVER (){

  pinMode(IN1_E, OUTPUT);
  pinMode(IN2_E, OUTPUT);
  pinMode(IN1_D, OUTPUT);
  pinMode(IN2_D, OUTPUT);
  pinMode(PWM_E, OUTPUT);
  pinMode(PWM_D, OUTPUT);
}

// Encoders

void doEncoderA();
void doEncoderB();
void doEncoder1A();
void doEncoder1B();

void start_ENCODER () {

  pinMode(encoder0PinA, INPUT); 
  pinMode(encoder0PinB, INPUT);
  pinMode(encoder1PinA, INPUT); 
  pinMode(encoder1PinB, INPUT); 

// Encoder Esquerda
  attachInterrupt(digitalPinToInterrupt(encoder0PinA), doEncoderA, CHANGE);
  attachInterrupt(digitalPinToInterrupt(encoder0PinB), doEncoderB, CHANGE);  

// Encoder Direita
  attachInterrupt(digitalPinToInterrupt(encoder1PinA), doEncoder1A, CHANGE);
  attachInterrupt(digitalPinToInterrupt(encoder1PinB), doEncoder1B, CHANGE);  
}

// SD card

void start_SD () {
  
  pinMode (CS,OUTPUT); 
  if (!SD.begin(chipSelect)) {
    Serial.println("Card failed, or not present");
    return;
  }
  Serial.println("card initialized.");
}

// Controle remoto

void start_RC(){
  pinMode(CHANEL1, INPUT);
  pinMode(CHANEL2, INPUT);
  pinMode(CHANEL3, INPUT);
  
}

//Funções driver--------------------------------------------------------------------------------------------------------------------------

void direita(int potEsquerda, int potDireita){
  analogWrite(PWM_E, potEsquerda);
  analogWrite(PWM_D, potDireita);
  digitalWrite(IN1_E, HIGH);
  digitalWrite(IN2_E, LOW); 
  digitalWrite(IN1_D, LOW);
  digitalWrite(IN2_D, HIGH);  
}

void esquerda(int potEsquerda, int potDireita){
  analogWrite(PWM_E, potEsquerda);
  analogWrite(PWM_D, potDireita);
  digitalWrite(IN1_E, HIGH);
  digitalWrite(IN2_E, LOW); 
  digitalWrite(IN1_D, LOW);
  digitalWrite(IN2_D, HIGH);  
}


void direita_eixo (int potEsquerda, int potDireita) {
  analogWrite(PWM_E, potEsquerda);
  analogWrite(PWM_D, potDireita);
  digitalWrite(IN1_E, HIGH);
  digitalWrite(IN2_E, LOW); 
  digitalWrite(IN1_D, HIGH);
  digitalWrite(IN2_D, LOW); 

}

void esquerda_eixo (int potEsquerda, int potDireita) {
  analogWrite(PWM_E, potEsquerda);
  analogWrite(PWM_D, potDireita);
  digitalWrite(IN1_E, LOW);
  digitalWrite(IN2_E, HIGH);  
  digitalWrite(IN1_D, LOW);
  digitalWrite(IN2_D, HIGH);

}

void frente(int potEsquerda, int potDireita){
  analogWrite(PWM_E, potEsquerda);
  analogWrite(PWM_D, potDireita);
  digitalWrite(IN1_E, HIGH);
  digitalWrite(IN2_E, LOW); 
  digitalWrite(IN1_D, LOW);
  digitalWrite(IN2_D, HIGH);  
}

void tras(int potEsquerda, int potDireita){
  analogWrite(PWM_E, potEsquerda);
  analogWrite(PWM_D, potDireita);
  digitalWrite(IN1_E, LOW);
  digitalWrite(IN2_E, HIGH);
  digitalWrite(IN1_D, HIGH);
  digitalWrite(IN2_D, LOW); 
}

void parar () {
  digitalWrite(IN1_E, LOW);
  digitalWrite(IN2_E, LOW);  
  digitalWrite(IN1_D, LOW);
  digitalWrite(IN2_D, LOW); 
}

void travar (){
  digitalWrite(IN1_E, HIGH);
  digitalWrite(IN2_E, HIGH);  
  digitalWrite(IN1_D, HIGH);
  digitalWrite(IN2_D, HIGH); 
}

//Funções Encoder -------------------------------------------------------------------------------------------------------------

void doEncoderA(){

  noInterrupts();
  // look for a low-to-high on channel A
  if (digitalRead(encoder0PinA) == HIGH) { 
    
    // check channel B to see which way encoder is turning
    if (digitalRead(encoder0PinB) == LOW) {  
      encoder0Pos = encoder0Pos + 1;         // CW 
    } 
    else {
      encoder0Pos = encoder0Pos - 1;         // CCW
    }
  }
  else   // must be a high-to-low edge on channel A                                       
  { 
    // check channel B to see which way encoder is turning  
    if (digitalRead(encoder0PinB) == HIGH) {   
      encoder0Pos = encoder0Pos + 1;          // CW
    } 
    else {
      encoder0Pos = encoder0Pos - 1;          // CCW
    }
  }
  interrupts();
}
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

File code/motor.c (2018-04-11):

#include <wiringPi.h>
#include <wiringSerial.h>
#include <fcntl.h>
#include <linux/input.h>
#include <unistd.h>
#include <signal.h>
#include <stdlib.h>
#include <termios.h>   // using the termios.h library
#include <stdbool.h>

#define LMOTOR 0
#define RMOTOR 1

#define ARDUINO_RST -1 // pin which will reset the Arduino board whenever the code starts

#define MSG_MAX 30
#define SEND_PRECISION 3
#define BAUDRATE 2000000

#define MEDIAN_SIZE_MOTOR 5

// Declaracao das funcoes.
void setupCommSerial();
void getValidData();
void storeValidData();
double getMediana_motor(double array[MEDIAN_SIZE_MOTOR]);

// Variaveis globais.
char msg[MSG_MAX];
bool newMsg = false;
int arduino;
double median_motor[MEDIAN_SIZE_MOTOR];
unsigned long long int now_time_motorL, now_time_motorR, old_time_motorL, old_time_motorR;

struct motor {
	double displacement, speed;
	double set_speed;
	unsigned long int last_update;
	unsigned long int n_disp, n_speed;
	double vec_speed[MEDIAN_SIZE_MOTOR];
	double vec_disp[MEDIAN_SIZE_MOTOR];
	double dt;
};

struct motor left_motor, right_motor;

void init_motors()
{
	int i = 0;
	char devpath[20];
	
	setupCommSerial();				// Setup comunicacao serial.

	unsigned long int now = micros();
	left_motor.displacement = 0;
	left_motor.speed = 0;
	left_motor.set_speed = 0;
	left_motor.last_update = now;
	left_motor.displacement = 0;
	left_motor.speed = 0;
	left_motor.set_speed = 0;
	left_motor.last_update = now;
	left_motor.n_speed = 0;
	left_motor.n_disp = 0;

	right_motor.displacement = 0;
	right_motor.speed = 0;
	right_motor.set_speed = 0;
	right_motor.last_update = now;
	right_motor.displacement = 0;
	right_motor.speed = 0;
	right_motor.set_speed = 0;
	right_motor.last_update = now;
	right_motor.n_speed = 0;
	right_motor.n_disp = 0;
}

void setupCommSerial()
{
	int ok = 0;

	do
	{
		arduino = serialOpen("/dev/ttyUSB0", BAUDRATE);	// Inicia comunicacao serial com baud rate 115200bps.
		//printf("no setup\n");
	} while (arduino <= 0);

	//while (wiringPiSetup() == -1);		// Necessita de sudo.

	do										// Espera a estabilizacao da comunicacao serial.
   	{
   		while(serialDataAvail(arduino))
   		{
   			msg[0] = serialGetchar(arduino);
   			//printf("%c...\n",   msg[0]);			// Apenas para testes.
   			if(msg[0] == 'c')						// Msg de nao recebimento.
   			{
   				serialPutchar(arduino, 'b');		// Reenvia msg de confirmacao de recebimento.
   			}
   			else
   			if(msg[0] == 'a')						// Msg esperada receber, envio e recibo de msg funcionando.
   			{
   				ok = 1;
   			}
   		}
   	} while (!ok);
}

static int lenght = 0;
void getValidData()
{
	static int msgp = 0;		// pontero da msg.
	char startChar = ':';		// char define inicio da msg.
	char endChar = ';';			// char define fim da msg.

	while((serialDataAvail(arduino)) && (!newMsg))
	{
		msg[msgp] = serialGetchar(arduino);
		//printf("%c\n", msg[msgp]);			// Apenas para testes.
		if (msg[msgp] == startChar)			// Ageita para comecar a colocar a msg no inicio de msg[].
		{
			msgp = -1;
		}
		else
		if (msg[msgp] == endChar)			// Finaliza a obtencao da msg encerrando a string msg[].
		{
			msg[msgp] = '\0';
			lenght = msgp - 1;
			newMsg = true;						// Sinaliza uma nova msg recebida.
		}
		
		msgp++;
		if (msgp >= MSG_MAX)				// Evitar a escrita em memoria inacessivel.
		{
			msgp = MSG_MAX - 1;
		}
	}
}

void storeValidData()	// Aqui que sera mudado para nossas necessidades. No caso espera receber apenas um float.
{
	if (newMsg)
	{
		//printf("msg: %s...\n", msg);
		if(msg[lenght] == 'l')
		{
			if(msg[lenght-1] == 'd')
			{
				left_motor.vec_disp[left_motor.n_disp%MEDIAN_SIZE_MOTOR] = atof(msg);
				left_motor.displacement = getMediana_motor(left_motor.vec_disp);
				left_motor.n_disp++;
				
				old_time_motorL = now_time_motorL;
				now_time_motorL = micros();
				left_motor.dt = (now_time_motorL - old_time_motorL)/1000000.0;
			} else if(msg[lenght-1] == 's'){
				left_motor.vec_speed[left_motor.n_speed%MEDIAN_SIZE_MOTOR] = atof(msg);
				left_motor.speed = getMediana_motor(left_motor.vec_speed);
				left_motor.n_speed++;
			}
		} else if(msg[lenght] == 'r') {
			if(msg[lenght-1] == 'd')
			{
				right_motor.vec_disp[right_motor.n_disp%MEDIAN_SIZE_MOTOR] = atof(msg);
				right_motor.displacement = getMediana_motor(right_motor.vec_disp);
				right_motor.n_disp++;

				old_time_motorR = now_time_motorR;
				now_time_motorR = micros();
				right_motor.dt = (now_time_motorR - old_time_motorR)/1000000.0;
			} else if(msg[lenght-1] == 's'){
				right_motor.vec_speed[right_motor.n_speed%MEDIAN_SIZE_MOTOR] = atof(msg);
				right_motor.speed = getMediana_motor(right_motor.vec_speed);
				right_motor.n_speed++;
			}
		}
		//valor = atof(msg);						// Transforma double, 0 para entradas invalidos.
		//printf("msg: %s...\n", msg);				// Apenas para testes.
		//printf("valor: %f...\n", velocidade);		// Apenas para testes.
		newMsg = false;
	}
}

void write_motors()
{
	char deliver[MSG_MAX];
	int i = 0;

	snprintf(deliver, MSG_MAX, ":%.*fl;", SEND_PRECISION, left_motor.set_speed);		// Prepara a msg a ser enviada.
	while (deliver[i] != '\0')
	{
		serialPutchar (arduino, deliver[i]);		// Envio da msg char por char ate fim da string. Obs: existe na biblioteca a funcao "serialPrintf" mas ela nao funcionou.
		//printf("%c", deliver[i]);
		i++;
		if (i >= MSG_MAX)							// Evitar ir alem da string.
		{
			break;
		}
	}
	//printf("\n");
	i = 0;
	snprintf(deliver, MSG_MAX, ":%.*fr;", SEND_PRECISION, right_motor.set_speed);		// Prepara a msg a ser enviada.
	while (deliver[i] != '\0')
	{
		serialPutchar (arduino, deliver[i]);		// Envio da msg char por char ate fim da string. Obs: existe na biblioteca a funcao "serialPrintf" mas ela nao funcionou.
		//printf("%c", deliver[i]);
		i++;
		if (i >= MSG_MAX)							// Evitar ir alem da string.
		{
			break;
		}
	}
	//printf("\n");
}

void setMotorSpeed(int motor, double speed)
{
	if(motor == LMOTOR)
	{
		left_motor.set_speed = speed;
	} else if (motor == RMOTOR) {
		right_motor.set_speed = speed;
	}
}



// Abdullah's QuickSort implementation for usage with the Median Filter
unsigned Partition_motor(double array[], unsigned f, unsigned l, double pivot)
{
    unsigned i = f-1, j = l+1;
    while(1)
    {
        while(pivot < array[--j]);
        while(array[++i] < pivot);
        if(i<j)
        {
            double tmp = array[i];
            array[i] = array[j];
            array[j] = tmp;
        }
        else
            return j;
    }
}

void QuickSortImpl_motor(double array[], unsigned f, unsigned l)
{
    while(f < l)
    {
        unsigned m = Partition_motor(array, f, l, array[f]);
        QuickSortImpl_motor(array, f, m);
        f = m+1;
    }
}

void QuickSort_motor(double array[], unsigned size)
{
    QuickSortImpl_motor(array, 0, size-1);
}
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

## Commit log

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2018-01-14 adicionado drive ao projeto do placa
    [principal.fzz]
2018-01-14 adicionado arquivo fzpz da placa PCA9685
    [principal.fzz]
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2018-01-16 todos os componentes da placa principal foram acressentados
    [principal.fzz]
2018-01-16 Added su check to main.c and set up wiringPi in Phys mode
2018-01-16 Added led support to main.c and adapted jstick.c interface with main for ease of maintenance
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2018-01-16 adicionando a placa do painel
    [painel.fzz, principal.fzz]
2018-01-16 adicionando a placa da alimentacao
    [alimentacao.fzz]
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2018-01-16 mudancao na placa prncipal
    [principal.fzz]
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2018-01-16 conexões da placa principal feitas no esquematico
    [principal.fzz]
2018-01-16 projeto da placa principal finaizado
    [principal.fzz]
2018-01-17 minor improvements
    [principal.fzz]
2018-01-17 adicionado txt para colocar links úteis na pasta de material de apoio
2018-01-17 projeto da placa alimentação finalizada
    [alimentacao.fzz]
2018-01-17 projeto da placa do painel finalizado
    [alimentacao.fzz, painel.fzz]
2018-01-17 pdfs dos circuitos gerados
    [painel.fzz]
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2018-01-17 pequena correção na logo da dorid no arquivo de impressão, de novo
2018-01-17 pequena correção na placa principal, arvo do fritiging
    [principal.fzz]
2018-01-18 pequena correção na placa principal, arquivos pdfs
    [principal.fzz]
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2018-01-20 Now compile_rasp.sh removed binary file after transfering file to the Raspberry Pi
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2018-01-23 Fixed several bugs concerning LED control
    [led.c, main.c, pca9685pwmcontrol.c]
2018-01-23 Tested and fixed motor driver code and hardware. Working fine.
    [main.c, motor.c]
2018-01-23 Added kill, shutdown and reboot routines through controller. Removed keyboard kill.
    [main.c]
2018-01-23 Version 2
    Actualizacion de los reguladores, step down
    [alimentacao2.fzz]
2018-01-23 pdf placa alimentação2
    [alimentacao2.fzz]
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2018-01-24 criado o programa observador para que possamos abrir e fechar o programa principal pelo joystic
2018-01-24 Began to redesign the whole debug infrastructure
    [led.c, main.c, motor.c]
2018-01-26 corrigindo pequeno erro no codigo do pbservador, que fazia com que o programa não esperece a trade do observador encerrar para fechar
2018-01-26 inicio do projeto da placa dos sensores
    [sensores.fzz]
2018-01-26 Began to modify led.c file to support LED states rather than simply colors
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2018-01-26 Renamed some of the variables and constant definitions under motor.c file and encapsulated all encoder readings into a struct for each motor.
2018-01-26 placa dos sensores finalizada
    [sensores.fzz]
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2018-01-27 Fixed LED init function bug
    [led.c]
2018-01-28 Many new features added, including:
    LED states fully operational.
    LED support completely modified to support LED states.
    SU check not believing the user anymore. Now checking with geteuid() function.
    Encapsulated the end of the main function in a clean_up() function.
2018-01-28 Minor modifications preparing for debug screen support. Added update_motors() function to calculate encoder measurements in meters.
2018-01-28 Added debug flag feature and debug screen. Still has some bugs to fix.
    [debug.c, main.c, motor.c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]
2018-01-30 Now the joystick thread coasts the motors before trying to reconnect controller
2018-01-30 Reversed encoder direction on the right motor
    [motor.c]
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2018-01-30 Fixed pin number definitions at testemotores.c file
    [testemotores.c]
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2018-01-30 Fixed motor bug. For the record: Coast and Brake functions were the source
    [main.c, motor.c]
2018-01-30 Added print_message() function for debug purposes and added IMU data to the debug screen
2018-01-30 Renamed last_update variable as last_led_update to avoid conflict
    [led.c]
2018-01-30 Now A, B and PWM values for each motor are updated every time a value is written to the pins. Mainly for debug purposes
2018-01-30 Added sensors thread to the main code and began to make sense of IMU data. WIP
2018-01-30 Added calibGyro.c program to get gyroscope offset values to write to offset registers
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2018-01-31 Debug screen mess up fixed
    [debug.c]
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2018-01-31 Redesigned IMU variable names for ease of use with debug screen and, in the future, with kalman filter.
    [sensors.c]
2018-01-31 Fixed bug in gyroscope. Still drifting a bit.
    [sensors.c]
2018-01-31 Alinhamento de algumas trilhas da placa
    [sensores.fzz]
2018-01-31 Arrumou um print que acontecia fora do modo de debug e tinha uma thread sem prioridade
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2018-02-01 Trying to find out what is bugging accel data processing
    [sensors.c]
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2018-02-01 Fixed minor bug when closing program with debug screen that caused terminal command line to appear in the middle of the screen
    [main.c]
2018-02-01 Added more lines to the debug screen available through the print_message() function and cleaned up the function itself.
2018-02-01 Added more prints using print_message() to try to figure out wtf is happening to the accelerometer.'
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2018-02-02 testes para descobrir erro da libmath na compilação cruzada , erro encontrado mas não corrigido ainda
    [main.c]
2018-02-02 Using much safer function (snprintf instead of sprintf) for prints under main_thread
2018-02-02 Uncommented some prints that were messing up the debug screen now that snprintf is being used
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2018-02-02 Adicionado pasta do compilador que funciona para cross compile. Retirado dos tools fornecido pelo raspberry.
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2018-02-02 usando atan2 para mostrar valor do acelerometro e soment o do atan2 em graus.
2018-02-02 corrigindo um eror de otimização
    [main.c, motor.c]
2018-02-02 Removed debug prints to clean up the mess caused by the math.h bug
    [main.c]
2018-02-02 Commented out atan() section of the accelerometer data processing and uncommented atan2() section
2018-02-02 Inverted all axes of the accelerometer
    [sensors.c]
2018-02-02 Added delay to avoid overloading CPU with main_thread
    [main.c]
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2018-02-02 Removed derivatives to avoid amplification of sensor noise
    [sensors.c]
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2018-02-03 Added soft reset on the magnetometer before configuring it
    [sensors.c]
2018-02-03 Enabled I2C bypass mode to access AK8963 directly through 0x0c I2C address
2018-02-03 Corrected mistake. Magnetometer sensitivity is read-only and probably factory-defined
    [sensors.c]
2018-02-03 Now reading out ST2 register of the magnetometer. Apparently it only gets next reading after reading that register
2018-02-03 Fixed misunderstanding of the AND operator.
    [sensors.c]
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2018-02-03 Put linear values in magnet angular velocity data temporarily for debug purposes
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2018-02-03 Fixed conceptual error in magnetometer calculations
    [sensors.c]
2018-02-03 Removed data ready check. Apparently not working properly.
    [sensors.c]
2018-02-03 Now magnetometer angular velocity debug screen prints are showing magnetometer measurements in milliGauss (I guess)
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2018-02-04 corrigindo os eixos dos três sensores para conhecidirem
    [sensors.c]
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2018-02-04 Fixed temporary usage of magnet.vel and accel.raw values to truly temporary variables
    [sensors.c]
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2018-02-05 corrigindo erro que fazia com que o servidor não conectasse com o cliente
    [debug.c, main.c]
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2018-02-05 corrigindo um erro que fazia com que o programa não fechasse quando o supervisório não fosse conectado
    [main.c]
2018-02-05 Fixed supervisory thread not closing, again.
    [main.c]
2018-02-05 Fixed bug where supervisory mode only would fail to update debug values
    [main.c]
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2018-02-08 corrigindo erros no enviu dos dados para o MATLAB
    [debug.c, sensors.c]
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2018-02-14 Fixed yaw and pitch directions (not really sure if according to standard)
    [sensors.c]
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2018-02-15 corrigi erro do viajente do tempo, na passagem de parametros para o MATLAB
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2018-02-15 corrigindo a comunicação com o processing
    [debug.c, sensors.c, supervisorio.pde]
2018-02-15 corrigindo o erro do out of bound
    [supervisorio.pde]
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2018-02-23 Removed useless variables from gyro struct and fixed dt vs imu.dt conflict. Now imu.dt is a double measured in seconds.
    [debug.c, main.c, sensors.c]
2018-02-23 Implemented GREENLIGHT state, tested out new motors and improved calibAccel output.
    GREENLIGHT state simply lights the LED up in green. For use while debugging flags.
    New motors are good for balancing but crap for racing. Too slow.
    The calibAccel.c code now outputs the mean X, Y, Z and Magnitude for the accelerometer.
    It was found out that the accelerometer is biased. Working on it.
    [calibAccel.c, led.c, main.c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]
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2018-02-26 gráficos para mostrar a interferencia dos motores no acelerometro
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2018-02-26 Now plot infrastructure creates indexed files to avoid overwriting previous measurements
    [main.c]
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2018-02-26 Implemented low-pass filter on the accelerometer. Still under testing.
    Also inverted BLUETOOTH and GREENLIGHT LED status priorities,
    updated watcher.c with the new way for closing programs and
    made changes to the way the programs (main and watcher) call each other.
    [led.c, main.c, sensors.c]
2018-02-27 Added median filtering to the accelerometer readings, hoping it will eliminate the accel vibrations.
    [sensors.c]
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2018-02-28 Fixed debug screen bug where IMU Time value was printed wrong.
    [debug.c, main.c]
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2018-03-02 Fixed magnetometer reading routine.
    Now the code checks for magnetometer DRDY bit to see if there is new data.
    [sensors.c]
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2018-03-10 adicionado a biblioteca do fabricante da IMU para usar o DMP.
    [HAL_FLASH.obj, HAL_PMAP.obj, HAL_PMM.obj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]
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2018-03-11 Added Arduino comm for received messages. Not working for negative numbers. Not sure why.
    [controle_velocidade.ino]
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2018-03-17 code working after hardware redesign
    [controle_velocidade.ino]
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2018-03-22 added reset timeout for the arduino to avoid integrator windup
    it also helps debugging comm
    built-in led lights up when timeout is reached and turns off when the arduino receives a serial message
    [controle_velocidade.ino]
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2018-03-30 comm and control now working together
    we still have to merge comm with the main code
    also closing issue #2
    [comunicacao_arduino.c, new_controle_velocidade.ino]
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2018-03-31 Little code corrections and changes
    [comunicacao_arduino.c, new_controle_velocidade.ino]
2018-04-01 Corrigindo pequeno erro na condição do wind up
    [new_controle_velocidade.ino]
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2018-04-10 Atualização das placas
    Foram feitas atualizações das de tres tipos de placas
    [alimentacao v3.fzz, painel v2.fzz, sensores v2.fzz]
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2018-04-10 Projeto da placa principal
    Projeto feito no Eagle versao 8
    [principal eagle.brd, principal eagle.sch]
2018-04-10 Library and final PCB
    Atualizaçao e versao final do projeto da placa PCB principal
    [principal eagle balancer final.brd, principal eagle balancer final.sch]
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2018-04-12 Corrigido plot falso ao desligar o código.
    [main.c]
2018-04-13 fixed bug where plotting would cause watcher not to be called
    [main.c]
2018-04-16 PCB final sensores 4/16/2018
    Corrigido erro de conexão de capacitor em curto
    [sensores v2.fzz]
2018-04-16 Versão final placa principal
    Corrigidas as trilhas que levan a tensão de 3.3 a 5V nos CI 7473 e 7404
    [principal eagle balancer final.brd, principal eagle balancer final.sch]
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2018-04-28 resetting many variables at the beginning of main_thread
    [main.c]
